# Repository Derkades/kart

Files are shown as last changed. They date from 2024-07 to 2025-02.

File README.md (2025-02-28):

# Kart

## Dashboard

Information and settings screen on steering wheel. PlatformIO project for STM32.

## Controller

Receives analog signal from acceleration/deceleration pedals (or rather, forwards and backwards pedals). The target speed/torque is sent to the two hoverboard controllers via serial, to ensure they both run at exactly the same speed.

## Hoverboard

Motor controllers (2x). For firmware see https://codeberg.org/raphson/hoverboard

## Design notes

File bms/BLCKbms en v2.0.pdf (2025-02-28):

# BLCKbms

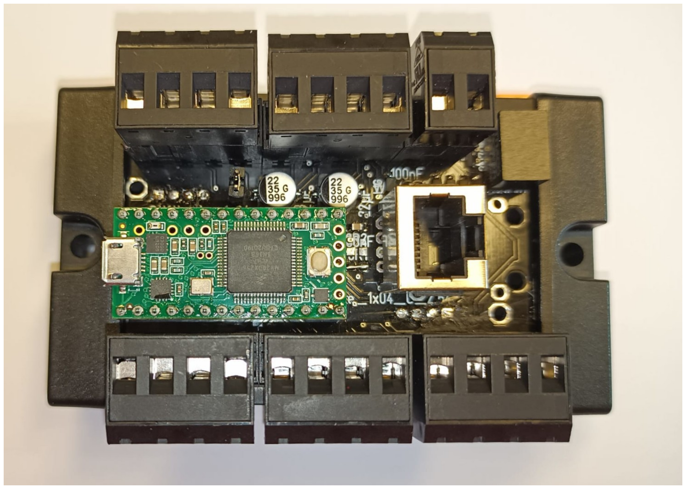
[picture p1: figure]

## 1 Table of Contents

## 2 Overview

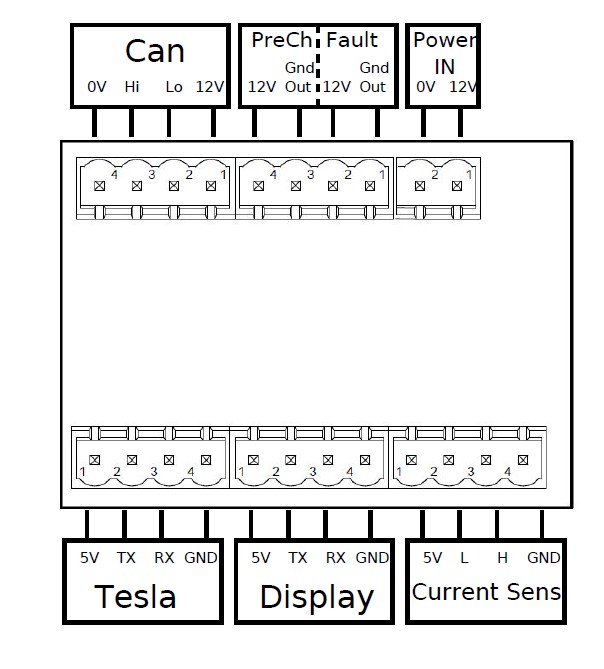
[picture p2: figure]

Manuel BMS Master | 2 von 4 | Ver 1.0

## 3 Interfaces for Second Life Batteries

The following interfaces are available with the BMS (see block diagram):

3.1 Tesla Interface

Connector BMS | Connector Tesla Modul
TX | 1. Modul PIN 2/7
RX | Last Modul PIN 4/9
+5V | PIN 5
GND | PIN 3

3.2 Can Interface:

Mitsubishi Outlander:

Connector BMS | Modul 1-x (Outlander) | Last Modul (Outlander)
12V | PIN 4 | PIN 4
GND | PIN 6 | PIN 6
Lo | PIN 1 | PIN 1 + PIN 8
Hi | PIN 5 | PIN 5 + PIN 2

BMW I3

Connector BMS | First I3 Pin | Next I3 Pin
5V | PIN 7 | PIN 1
GND | PIN 12 | PIN 6
Lo | PIN 10 | PIN 4
Hi | PIN 11 | PIN 5

Victron Wechselrichter

Connector BMS | Victron RJ45 | Aderfarbe Patchkabel
12V | PIN 2 + PIN 4 | orange + blue
GND | PIN1 + PIN 5 | blue/white + orange/white
Lo | PIN 8 | brown/white
Hi | PIN 7 | brown
Manuel BMS Master | 3 von 4 | Ver 1.0

## 4 Fault Output

This output switches in the event of overvoltage, undervoltage, overtemperature or undertemperature. With this output, the battery is to be switched off via a suitable switching device. The output (Out) is ground-switching. If a relay is connected, free-wheeling diodes have to be used.

## 5 PreCharge Output

## 6 Current sensor:

Connection Current Sensor: LEM DHAB S/161

Connector BMS | Connector | Description
L | D | Vout low current range
GND | C | GND
H | B | Vout high current range
5V | A | 5V
Manuel BMS Master | 4 von 4 | Ver 1.0

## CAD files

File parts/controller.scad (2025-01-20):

include <BOSL2/std.scad>

height = 100;
width = 170;
t = 0.8;
depth = 35;

difference() {
    union(){
        cuboid([width, height, t], anchor=BOTTOM);
        rect_tube(h=depth, size=[width+t*2, height+t*2], isize=[width, height], anchor=BOTTOM);

        up(depth-12.5)
        right(width/2)
        yrot(45)
        cuboid([20, height, t], anchor=TOP+RIGHT);
    }
    
    up(depth-12.5)
    right(width/2)
    yrot(45)
    cuboid([100, height+2*t, 20], anchor=BOTTOM);
    
    up(depth)
    cuboid([width, height, 10], anchor=BOTTOM);
}

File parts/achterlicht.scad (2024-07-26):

include <BOSL2/std.scad>

iw = 100;
ih = 52 + 2;
h = 10;
wall = 2;

// Kies een van de twee
//plate();
box();

module box() {
    difference() {
        cuboid([iw+wall*2, ih+wall*2, h], anchor=BOTTOM);
        
        translate([0, 0, wall])
        cuboid([iw, ih, h], anchor=BOTTOM);
        
        // tie wrap and cable holes
        for (x = [-iw/3, 0, iw/3]) {
            translate([x, -ih/2, 0])
            cuboid([6, 1.7, wall], anchor=BOTTOM+FRONT);
        }
    }
}

module plate() {
    translate([0, 0, h-wall/2])
    difference() {
        cuboid([iw, ih, wall/2], anchor=BOTTOM);
        
        // tie wrap holes
        for (x = [-iw/3, iw/3]) {
            translate([x, -ih/2, 0])
            cuboid([6, 1.7, wall/2], anchor=BOTTOM+FRONT);
        }
    }

}

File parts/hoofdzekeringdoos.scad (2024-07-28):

include <BOSL2/std.scad>

module screw_mount(hole_r, t) {
    difference() {
        cube([hole_r*4, hole_r*4, t], anchor=BOTTOM);
        cylinder(h=t, r=hole_r, anchor=BOTTOM);
    }

    for (y = [-hole_r*2+t/2, hole_r*2-t/2]) {
        translate([0, y, t])
        prismoid(size1=[hole_r*4, t], size2=[0, t], shift=[-hole_r*2, 0], h=hole_r*3);
    }
}

h = 30;
ol = 85;
ow = 35;
t = 2;
cutout_width = 15;
cutout_top_distance_from_left = 5;
cutout_height = cutout_width + h / 4;
screw_r = 2.5;

difference() {
    cube([ol, ow, h], anchor=BOTTOM);

    translate([0, 0, -t])
    cube([ol-t*2, ow-t*2, h], anchor=BOTTOM);

    // Left and right cutout
    for (x = [ol/2-t/2, -ol/2+t/2]) {
        translate([x, 0, 0])
        cube([t, cutout_width, cutout_height], anchor=BOTTOM);
    }
    
    up(h-1)
    fwd(5)
    scale(0.9)
    linear_extrude(2)
    text("hoofdzekering", anchor=BOTTOM);
}

// Screw mounts right
for (y = [ow/2-screw_r*2, -ow/2+screw_r*2]) {
    translate([ol/2+screw_r*2, y, 0])
    screw_mount(screw_r, t);
}

// Screw mounts left
for (y = [ow/2-screw_r*2, -ow/2+screw_r*2]) {
    translate([-ol/2-screw_r*2, y, 0])
    zrot(180)
    screw_mount(screw_r, t);
}

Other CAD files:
parts/spatbord.scad
parts/stuurscherm.scad

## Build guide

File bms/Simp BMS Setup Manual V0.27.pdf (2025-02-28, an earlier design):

SIMP BMS V2.3 | SimpEco Engineering
2021-08-20
simpecoeng@gmail.com | 1

# SIMP BMS

Manual V0.27

## Contents

Settings modified by sending “ ‘ID’ ‘New Value’ ” via the serial terminal, will refresh values in

## Disclaimer

Please read this manual and understand it, questions are allowed. You the purchaser of this product are responsible for installing this system yourself. You NEED knowledge of battery systems, automotive wiring and general computer knowledge.

THIS IS NOT A PLUG AND PLAY SYSTEM, USER CONFIGURATION AND WIRING REQUIRED

The device is provided "as is". Simp Eco Engineering makes no warranties, expressed or implied, and hereby disclaims and negates all other warranties, including without limitation, implied warranties or conditions of merchantability, fitness for a particular purpose, or non-infringement of intellectual property or other violation of rights. Further, Simp Eco Engineering does not warrant or make any representations concerning the accuracy, likely results, or reliability of the use of the materials in this manual or otherwise relating to such materials.

Damages
In no event shall Simp Eco Engineering or its suppliers be liable for any damages (including, without limitation, damages for loss of data or profit, or due to business interruption,) arising out of the use or inability to use the devices supplied by Simp Eco Engineering, even if Simp Eco Engineering or a Simp Eco Engineering authorized representative has been notified orally or in writing of the possibility of such damage.

Please contact the reseller that has provided you the SimpBMS first for support

## SimpBMS Purchase Overview

The standard items included in the purchase of a SimpBMS are:

- The SimpBMS board
- Teensy 3.2 flashed with requested Firmware

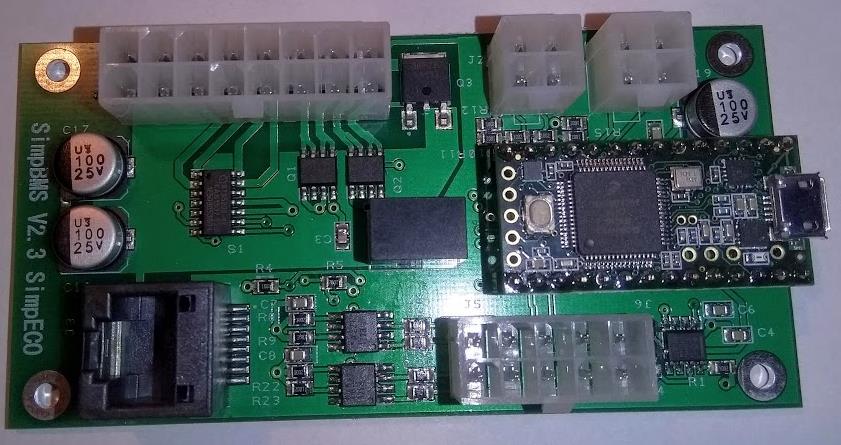
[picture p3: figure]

Optional available hardware at extra cost:
- Mating Connectors to the SimpBMS board with terminals

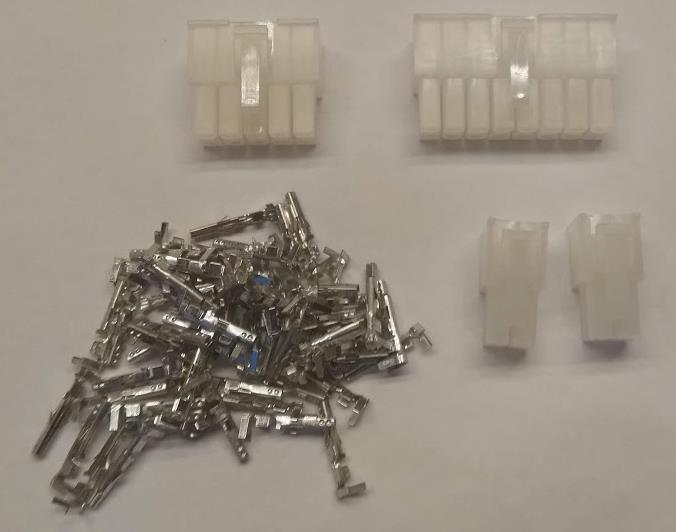
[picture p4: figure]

- Nextion 3.2 Inch Display with flylead, loaded with software to work with SimpBMS

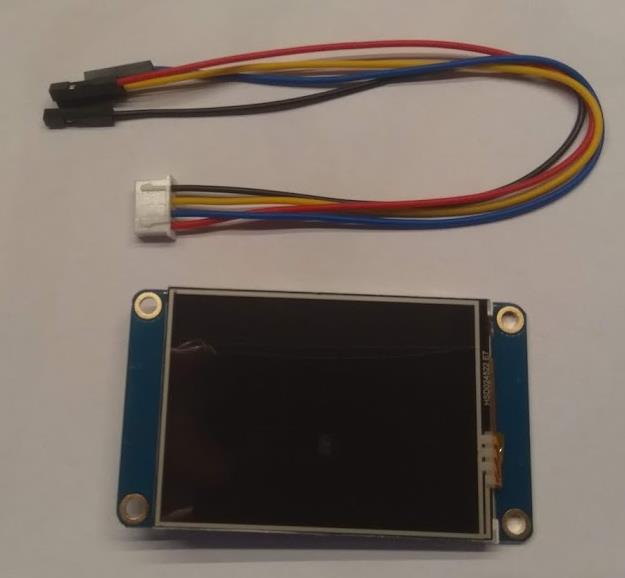
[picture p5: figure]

## Basics of the SIMP BMS

The starting point for this BMS is to keep it simple, the BMS will not prevent you from harming your battery if you do not set it up properly or ignore the limits it sends out.

### Currently supported slaves:

-Tesla Model S/X
-Tesla battery modules used in other OEM cars
-VW E-Golf and GTE (no balancing currently) -Mitsubishi Outlander
-BMW I3
-BMW Phev
-Chevy Volt / Opel Ampera Gen1

### Features:

Teensy 3.2 based
4 - 5-16V isolated inputs
4 - 12V outputs
4 - Low side switching outputs
2 - analogue current inputs (for dual range sensor)
1 - Serial bus for Tesla modules
1 - Canbus for communication with other modules, current senors or vehicle 1- Spare serial bus for expansion

### Current working features:

- Canbus communication formatted for Victron Systems
- Full Control of Slaves, reading temperatures and voltages plus controlling balancing
- Precharge control, timer and current based
- Can based current sensor (CAB300)
- AH Counter Based SOC calculation
- Voltage based SOC correction
- Watchdog timer to reset BMS in event of software error
- Canbus Chargers (Brusa NLG5xx, Chevy Volt, Elcon) -Display support (Nextion)

### Working Modes

Normal Operation (EV)

This mode will function as you would expect from a ‘key’ operated pack, such as found in vehicles. Precharge will happen with key on ect.

ESS Mode (stationary)

Specifically developed to cater to the needs of stationary or large packs
(dual purpose packs on boats for example)
When powered up Precharge occurs (no key in used) then contactors/relays used to control charge and discharge allowed. Also a Shunt trip or Main contactor output to disconnect packs when issues occur.

All features beyond output and input control are identical.

## Work in Progress

### EVSE controls

An interface circuit is being developed to allow the SimpBMS to directly interface with an EVSE via the Control Pilot line.

This will use the following pins (you can use more then one source of signal if needed)

1. AC present, 12V high when EVSE active and plugged in
2. Input 4 to sense duty cycle of the CP signal
3. Charge enable to request power from the EVSE

Functionality currently looking at supporting:

1. Enabling EVSE and charger if values allow
2. Managing the DC current limit based on AC current and Battery limits

## Detailed Workings

### Balancing

There is a small difference between ESS Mode and Normal Operation;

-ESS Mode always allows balancing based on balancing settings

-Normal Operation does not balance while in ‘driving’ operation state, this is due to the possibility of large voltage fluctuations due to high variation of loads.

For the working of balancing please see the setup page with the relevant parameters; Serial Interface / ‘b’ Battery Settings Menu

## Wiring Basics

Before starting on wiring your SimpBMS configuration it is best to get an understanding of the major components in your setup.

Ask yourself the following questions:

1. Do I want to have a EV or Storage (ESS) application
2. What devices are to be connected to the canbus network
a. Do these devices communicate at the same speed (example: 500KBPS) (see canbus chapter page 38)
b. Do these devices have canbus terminators in them
3. Will the BMS control the Contactors (see contactors chapter page 17)
4. What other inputs and outputs do I need (see inputs chapter page 19)

The most basic storage setup will have the following:

1. 12V power and ground into the SimpBMS connector J4
2. Battery module slaves connected to connector J5, see the specific page for each supported version
3. Connector J5 or J3 used to have canbus communication to the rest of the system, for example a Victron GX product

All other features can be considered “add-ons” getting the basic setup communicating properly is important to troubleshoot wiring and setting issues.

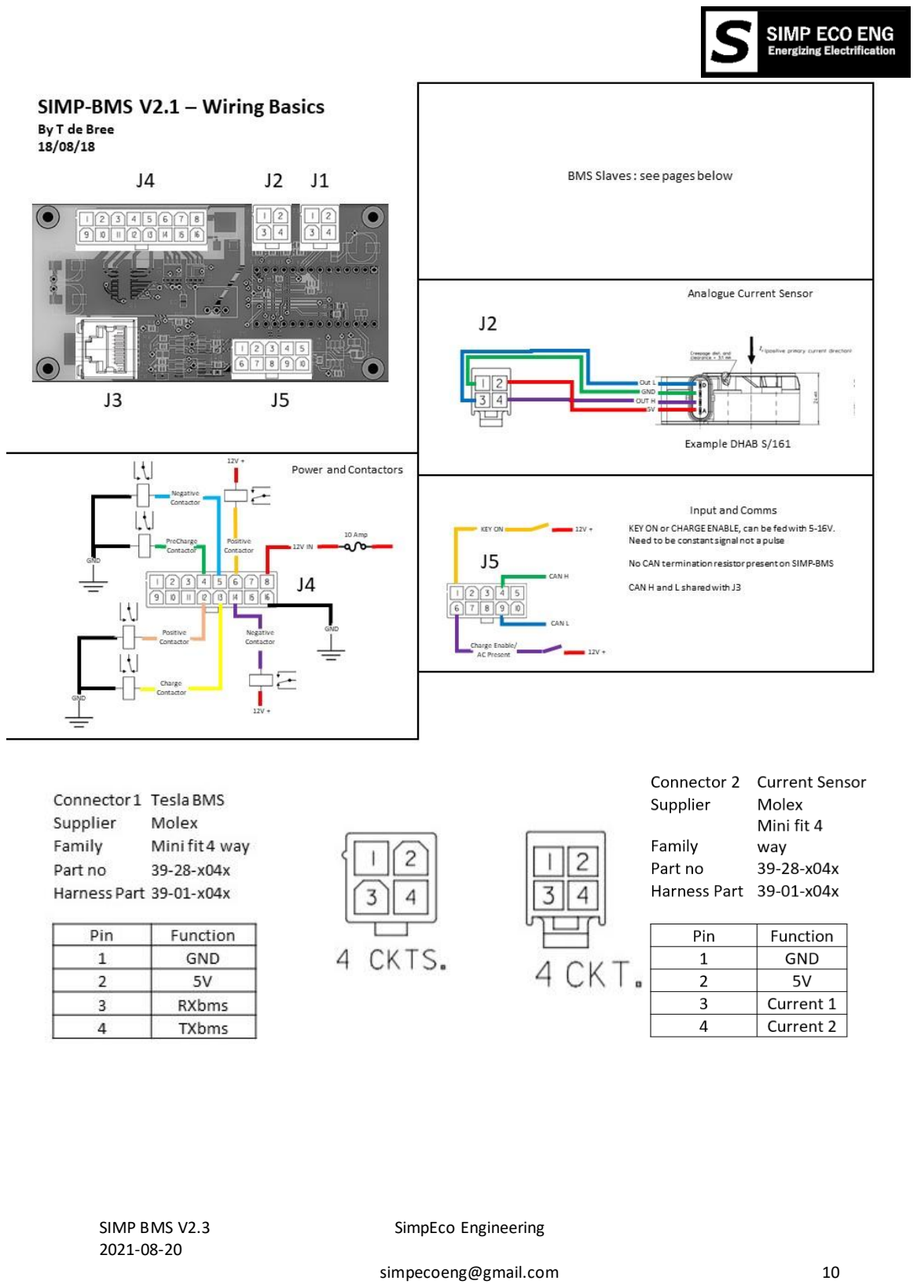
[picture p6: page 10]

2021

-08

-20

2021

-08

-20

Connector 5 Comms
Supplier | Molex
Family | Mini fit 8 way
Part no | 39-28-x10x
Harness Part 39-01-x10x
Pin | Function | Switching | Type | V2 Normal usage | ESS Mode | Function | Pin | Pin | Function 1 | In 1 | High | Input | Key on | Storage Mode | In 3 | 6 | 1 | In 1 2 | In 2 | High | Input | Alt Charge Current | - | In 4 | 7 | 2 | In 2 3 | Txspare | - | Comms | - | - | Rxspare | 8 | 3 | Txspare 4 | CanH | - | Comms | Can | Can | CanL | 9 | 4 | CanH 5 | 5V Out | - | Supply | - | - | GND | 10 | 5 | 5V 6 | In 3 | High | Input | AC present | - 7 | In 4 | High | Input | CP cond signal | - 8 | Rxspare | - | Comms | - | - 9 | CanL | - | Comms | Can | Can
10 | GND | - | Ground

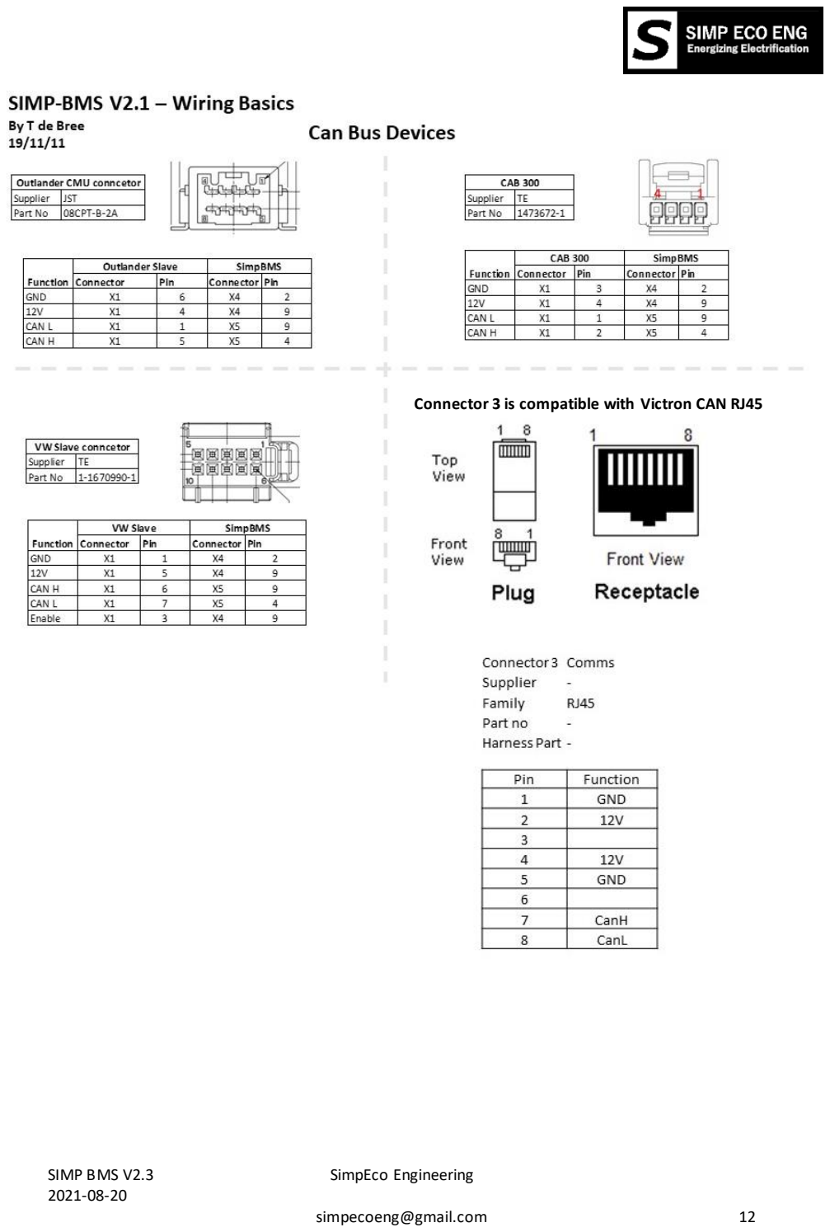
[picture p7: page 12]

Connector 3 is compatible with Victron CAN RJ45

### Tesla Slave Wiring

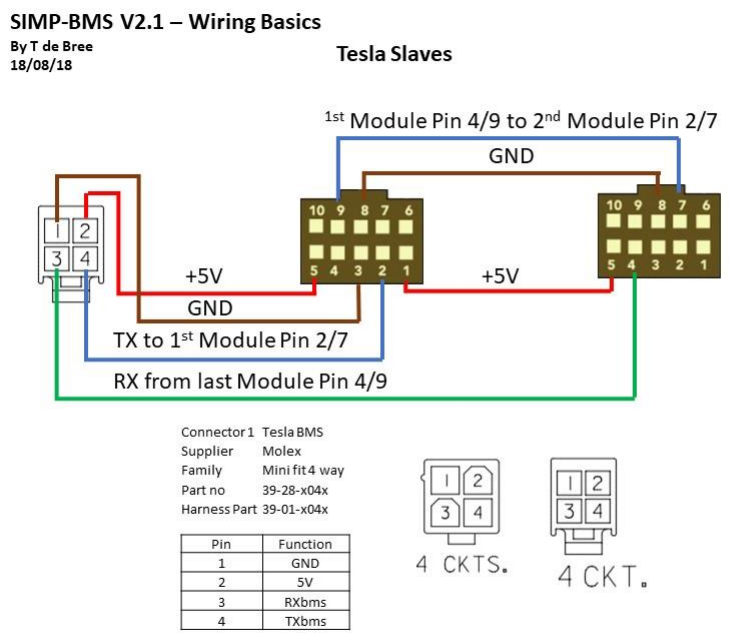
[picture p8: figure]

### Chevy Volt Gen1 Slaves

The battery master, located in front of the Chevy Volt Gen 1 pack is connected to the internal network with the slaves and current sensor.

Connector looks as below:

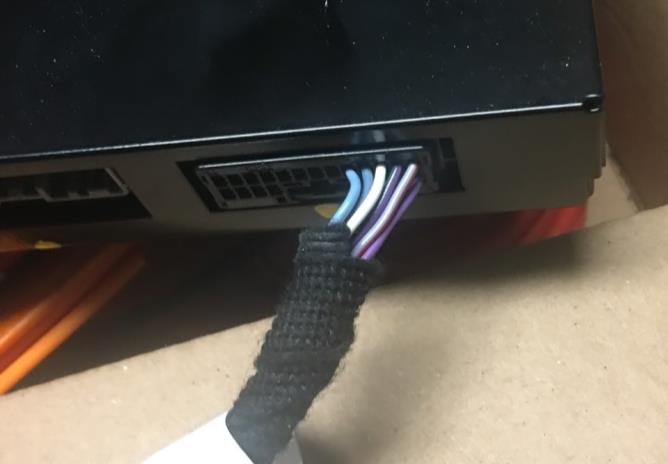
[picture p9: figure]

BMS Slaves

Pin | Function | Color | SimpBMS connection
9 | 5V supply | Grey/Red | J5-5
10 | Ground | Black/Purple | J5-10
11 | Can Low | White Yellow | J5-9
12 | Can High | Light Blue/Yellow | J5-4
13 | - | Light Blue | -

Current Sensor - dhab s44

Pin | Function | Color | SimpBMS connection
1 | 5V supply | Purple/Red | J2-2
2 | Ground | Black/Grey | J2-1
3 | High Range | Light Blue/Yellow | J2-3
4 | Low Range | Light Green/Brown | J2-4

Configuration:

Current Sensor Type: Dual Range

Low Range : 100 mV/A

High Range : 6.15 mV/A

### Mitsubishi Outlander CMUs

Up to a full pack can be used, it is not possible to use more because of the assigned Can Bus Ids per module.

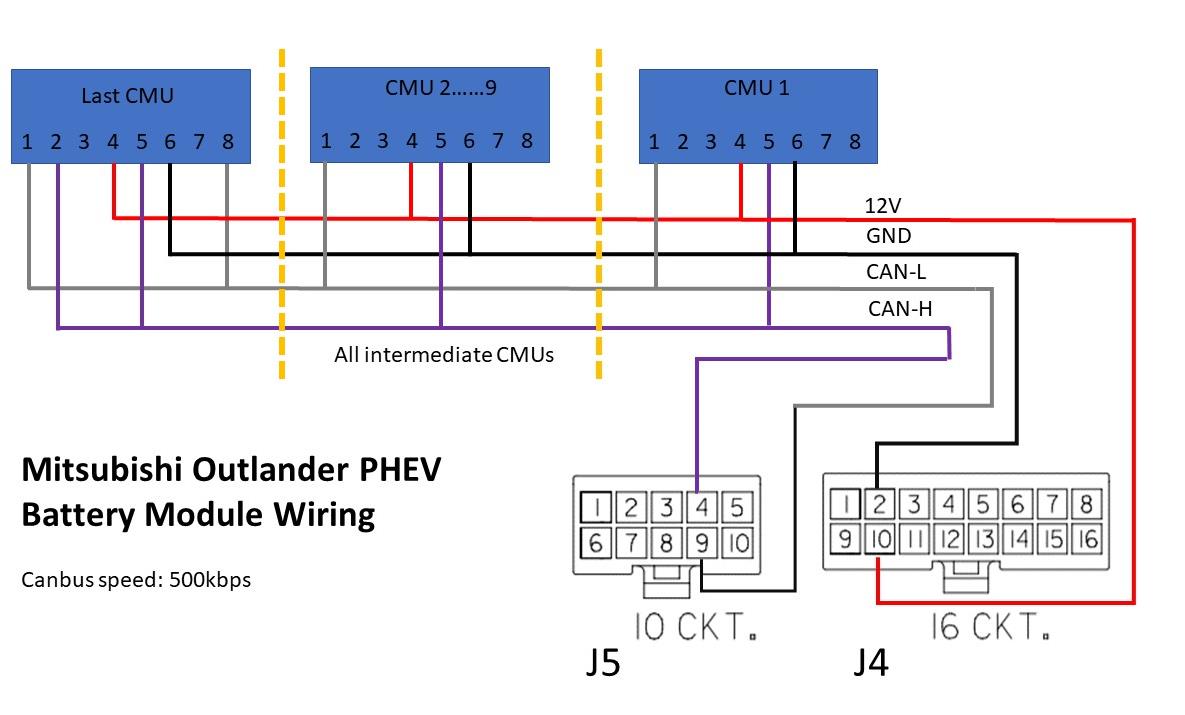
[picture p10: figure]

### BMW I3 CSC modules

Up to a full pack can be used, it is not possible to use more because of the assigned Can Bus Ids per module.

wiring
Designed to be Daisy chained from one module to the next, remember to close the end canbus by having a 120 ohm resistor between canH and canL.
BMW I3 Pin | Function | Color | SimpBMS connection
1 | 5V supply | Grey/Red | J5-5
6 | Ground | Black/Purple | J5-10
4 | Can Low | White Yellow | J5-9
5 | Can High | Light Blue/Yellow | J5-4

If using more then one module you can just do the following:

First BMW I3 Pin | Function | Next BMW I3
7 | 5V supply | 1
12 | Ground | 6
10 | Can Low | 4
11 | Can High | 5

If you use the full pack you can interface to the “Master” connector

Master plug pin | Function | Colour | SimpBMS connection
5 + 11 | 5 V supply | Red/white | J5-5
6 + 12 | Ground | White/brown | J5-10
8 | Can low | Yellow/brown | J5-9
7 | Can high | Yellow/red | J5-4
1 + 2 | Resistor 120 ohm | Yellow/brown and Yellow/red | 120 Resistor between

Extra info on individual module slaves

| BMW i3 Slave Connector
Function | 5V Power | | ? | CanL | CanH | GND
Wire | Red/White | NC | Blue | Yellow/Brown | Yellow/Red | White/Brown
Pin | 1 | 2 | 3 | 4 | 5 | 6
Pin | 7 | 8 | 9 | 10 | 11 | 12
Wire | Red/White | NC | Blue | Yellow/Brown | Yellow/Red | White/Brown
Function | 5V Power | | ? | CanL | CanH | GND

## Outputs and Inputs

### Contactors

It is possible to use both contactors with built in economizers or without.

Contactors with built in economizers MUST be used on the 12V switched outputs

Contactors without built in economizers MUST be used on the ground switched PWM outputs

See for the circuit below, a diode must be used in parallel with the contactor.

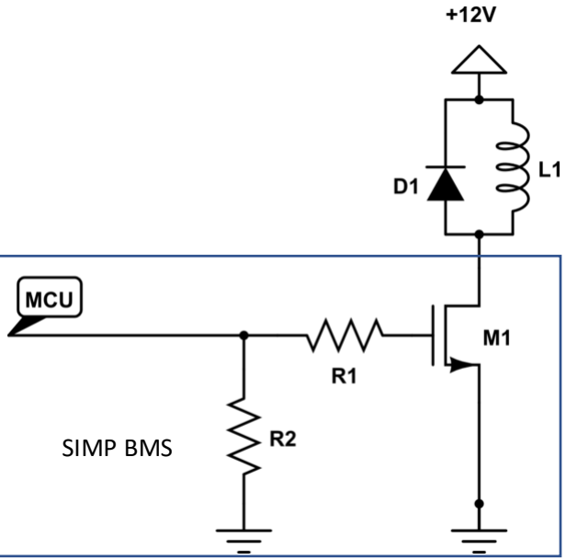
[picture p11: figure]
SIMP BMS

### Contactor behavior

ESS Mode:

Delay on the Low switching contactor outputs can be set via precharge delay

Function | Switching | Pin | ESS switching behaviour
Charge | High | 13 | Instant
DisCharge | High | 12 | Instant

These outputs are meant to control dumb loads and chargers/sources.

The other outputs to ‘Trip Shunt’ or ‘Main Contactor’ mode

### Trip Shunt

In ESS mode OUT2 can be used to trip DC breakers with a shunt trip device. This output goes high when an over or under voltage or over temperature situation occurs.

Make sure the shunt is rated for the activation signal of 12V.

Function | Switching | Pin | ESS switching behaviour
Shunt Trip | High | 4 | Instant
Not Used | High | 5 | NOT USED

### Main Contactor

In ESS mode you can choose to have a single contactor to connect and disconnect the battery.

When an over or under voltage or over temperature situation occurs the battery gets disconnected. If these faults are not present the battery is allowed to connect.

Function | Switching | Pin | ESS switching behaviour
Main Contactor | High | 4 | Switches on after precharge
Main Contactor | Low | 6 | Switches on after precharge
Precharge | High | 5 | Switched on for duration of precharge delay

### Inputs

Inputs are triggered by giving them anywhere from 5-16V, the inputs are isolated from the micro controller but must share the same ground as 12V in.

EV Mode:

Pin | Name | Function
1 | Key-on | Request BMS to close contactors and go into ‘Drive’ mode via precharge
6 | AC-present | Request BMS to go into charge mode and command charger
2 | Charge Current | Not connected – standard limit / HIGH is alternate limit
7 | CP conditioned | Control Pilot signal monitoring (future implementation)

ESS Mode:

Pin | Name | Function
1 | Storage Mode | Charge Voltage now reduced to parameter ‘Storage Setpoint’

### Wiring contactors into BMS or Not

Depending on your setup you can decide to have the contactors controlled by the BMS or by the Inverter/Drive unit.

Please keep in mind:

- Tripping contactors with rotating motors can/will damage the inverter
- The BMS is meant to protect the batteries and not other items
- Wiring items directly to the battery can cause drain that can irreversibly damage the batteries.

If your motor controller/inverter can control the contactors use this. Wire the BMS positive contactor 12V output to control a relay that can cut the enable signal to the motor controller/inverter to protect the batteries. This signal can also be used for a ‘Ready’ light on the dash for a visual indication.

Depending on the charger you can wire it directly to the battery or via a single contactor depending on the type of charger used, some require pre-charging.

### Wiring up BMS Slaves

When reusing existing vehicle battery modules might not be possible to parallel them at cell level.

The approach that thus can be taken is to wire all the modules in series and then parallel the strings to create the complete pack.

Values to determine for your setup:

Battery Capacity – Capacity of parallel cells monitored by BMS Slave

slaves in parallel – How many battery strings are connected in parallel

Cells in Series – total amount of cells that are in series in a string

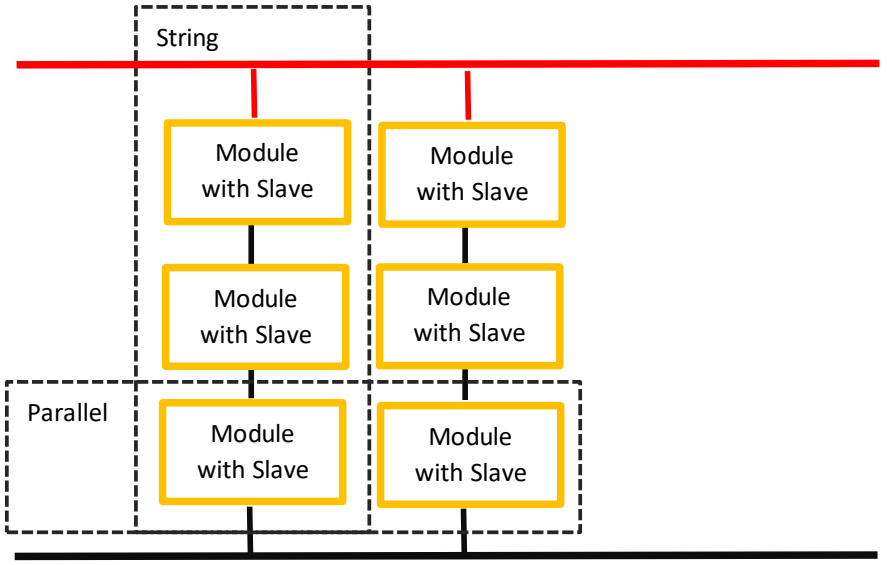
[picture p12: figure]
String; Module with Slave; Parallel

### Wiring up Nextion Display

A Nextion Display programmed with the appropriate software will allow the displaying of information provided by the SimpBMS.

The required connections are on connector 5.

Connector 5 | Signal BMS | Connection Display
5 | 5V supply | 5V
10 | Ground | Ground
3 | RXspare | TX
8 | TXspare | RX

Nextion Display Connection

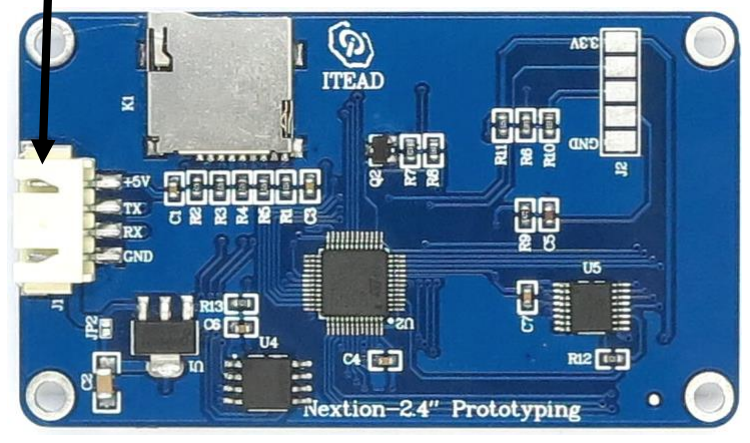
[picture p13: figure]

### Upgrading Nextion display firmware

There are two ways to do this;

1. Utilizing the Nextion editor and provide .HMI file found here: https://github.com/Tom-evnut/SimpDisplay
2. Saving the “.tft” file onto an SD card, insert into display, power cycle display and wait for update to complete.

### Wiring up Chargers

SimpBMS can control chargers in various ways:

- Simple on/off control with a relay
- Can bus controlled with a relay as back up (Can Bus info in the Can Bus Chapter)

Depending on how your charger is connected to your pack you can enable the HV contactors closing if required.

Below is an simplified diagram, this is for illustration only.

If the charger is directly connected to the battery, like the green lines show, the contactors do not need to close in order to charge.

The variable ; Charger HV Connection would be set to Direct To Battery HV

If the charger is connected to the HV bus after the contactors, the blue lines;

The variable ; Charger HV Connection would be set to Behind Contactors

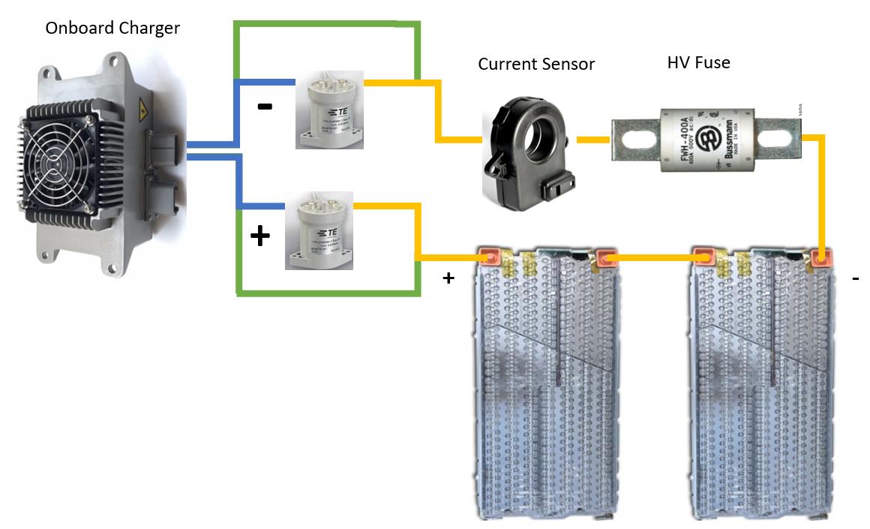
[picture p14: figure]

### Connection to Victron Color Control

Connector 3 on the SimpBMS is compatible with the VE.Can rj45, this means that you can use a standard ethernet cable to join the two. Please bear in mind that for VE.Can to work it requires a termination resistor to be added on the second VE.Can port on a color control.

Victron VE.Can terminator: https://www.victronenergy.com/accessories/ve-can-rj45-terminator

The SimpBMS will still require to be powered by an external 12V source.

Example connection to a Color Control GX

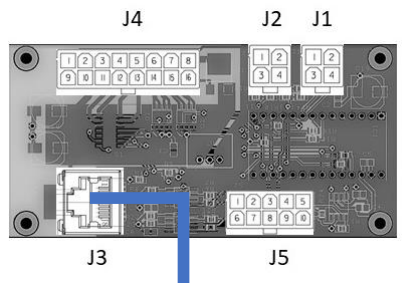
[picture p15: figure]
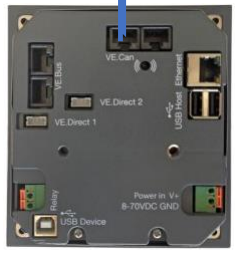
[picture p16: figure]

The GX control needs to be configured to 500kbps so it can receive the data from the SimpBMS.

The SimpBMS should show up as an available Battery monitor on the GX.

A good start for further workings of a Can based BMS in the Victron system : https://www.victronenergy.com/live/ccgx:start

## Serial Interface

How to connect to SIMP BMS.

1. Connect the Micro-B USB port on the teensy to your computer with appropriate cable
2. Computer should identify new usb/serial device
3. Open your preferred Serial Terminal Program. Example : https://www.compuphase.com/software_termite.htm
4. Connected to the Simp BMS via the serial port (115200 BAUD)
5. Now you should see the ‘Debug’ screen info scrolling

Any issues with connecting please check the Teensy Microcontroller troubleshooting guide:

https://www.pjrc.com/teensy/troubleshoot.html

If the Teensy does not show up as serial port please run the Teensy Serial installer https://www.pjrc.com/teensy/serial_install.exe

### Diagnostic Info Screen

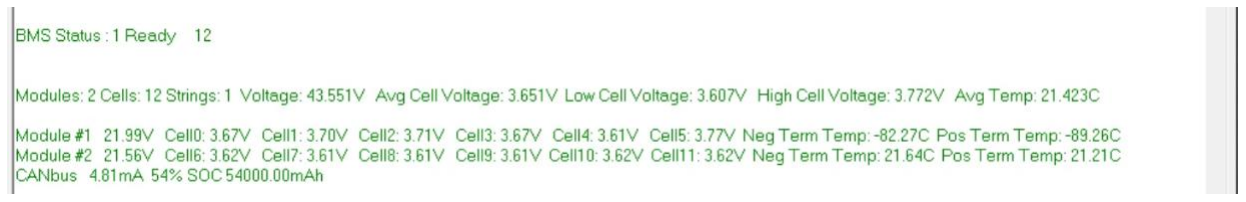
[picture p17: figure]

BMS Status : this is what state the bms is in.

Ready : BMS is good and communicating normally, waiting for a drive or charge digital input

Mode that is suggested for a fixed storage solution

Error : A fault is present in the read out from the modules. Possible issues:

Overvoltage

Under voltage

Overtemperature

Under temperature

Precharge : when Key on is high this is initiated, drives the negative contactor and then the precharge contactor. Once Precharge Timer (5000mS) has ran out AND the current drops below 1000mA it will close the contactor.* This initiates transition into drive.

Drive : Monitors voltages and temperatures with negative and positive contactor closed.

If key on signal goes low both contactors turn off immediately and BMS goes into Ready state.

Transition to error state if : under voltage is detected

Temperature currently only derates the transmitted current limits

Charge: When AC present in is high the charger enable output gets turned on until end of charge is reached or error occurs.

When one cell hits the overvoltage it will stop charging and go to ready.

Rest of displayed information is shown per module, both voltage and temperatures reported

Plus a summary of totals and averages based on pack settings

To open setup send the command: s

### Simp BMS Setup Menu

Not al variants have the same parameters or menus.

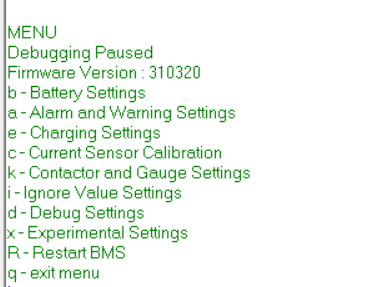
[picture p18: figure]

This stops the scrolling of the diagnostics info.

This shows the Firmware Version Number, please indicate this when ever requesting support.

And displays the following options:

b - Battery Settings

a - Alarm and Warning Settings

e - Charging Settings

c - Current Sensor Calibration

k – Contactor settings and Gauge Settings

i – Ignore Value Settings

d - Debug Settings

x-Experimental Settings

R – Restart BMS

q - exit menu

### ‘q’ Quit

Exit the setup menu and resume diagnostics display info

### ‘d’ Debug Settings

Inputting a number of the shown options toggles the modes, to stop send the same number.

1 – Can Debug = show can messages

2 – Current Debug = show all the current calculation information

3 – Output Check = cycle outputs !!! DO NOT TURN ON WITH HV CONNECTED TO CONTACTORS

4 – Input Check = show level of all inputs

5 – ESS Mode = turn on and off ESS Mode, ON is 1

6 – Cells Present Reset = recalibrate the cells to check if they are present

7 – Gauge Debug = cycle the gauge output up and down for testing pwm settings for gauge

8 – CSV Debug = Data is now displayed in a Comma Seperated Values makes logging it easier

9 – Decimal Places to Show = how many decimals to show for cell voltage debug

q – go back a menu

### ‘b’ Battery Settings Menu

Settings modified by sending “ ‘ID’ ‘New Value’ ” via the serial terminal, will refresh values in terminal

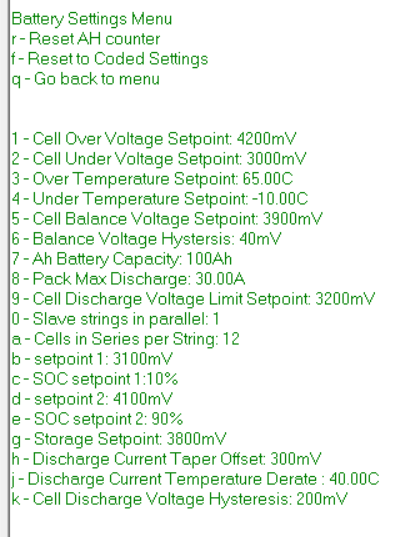
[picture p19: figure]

r – Reset AH Counter = Use voltage to determine SOC, best used with open circuit voltage

f – Reset to coded settings, the settings that were written when the code was compiled

1 – Over Voltage Setpoint = Over voltage limit per cell in mV

2 – Under Voltage Setpoint = Under voltage limit per cell in mV

3 – Over Temperature Setpoint = Setpoint at which allowed discharge and charge current is reduced to zero

4 - Under Temperature Setpoint = Setpoint at which allowed discharge and charge current is reduced to zero

5 – Balance Voltage Setpoint = Setpoint of cell voltage in mV at which during charging cells will start balancing.

6 – Balance Voltage Hysteresis = Voltage required to be above the lowest cell to allow balancing of cell in mV

7 – Battery Capacity = each group of parallel cells monitored per slave capacity in Ah

8 – Max Discharge = maximum discharge current in A, transmitted current limit will taper from max current starting at discharge temp to zero at over temperature.

9 – discharge voltage limit = used to calculate max discharge setpoint, voltage per cell will get converted to pack level by BMS

0 – slaves in parallel = amount of slave strings in pack (will multiply total pack capacity)

a – cells in series = amount of cells in series (per string if wired in parallel)

b - mV setpoint 1 = cell voltage setpoint 1 for voltage based SOC calc

c - SOC setpoint 1 = SOC for corresponding cell voltage

c- mV setpoint 2 = cell voltage setpoint 2 for voltage based SOC calc

e- SOC setpoint 2 = SOC for corresponding cell voltage

g – Storage Charge Voltage setpoint = when in Storage mode in ESS this is used instead of Charge Voltage Limit

h – Discharge Current Taper Offset = the voltage offset from Discharge Voltage Limit at which the discharge current Max will start to taper down.

j – Discharge Current Temperature Derate = Temperature above which discharge current starts to taper to 0 Amps at Over Temperature

k – Cell Discharge Voltage Hysteresis = cell voltage needs to rise this amount above the Discharge Voltage Limit before discharge is allowed again in ESS mode

### ‘e’ Charging Settings

Settings modified by sending “ ‘ID’ ‘New Value’ ” via the serial terminal, will refresh values in terminal

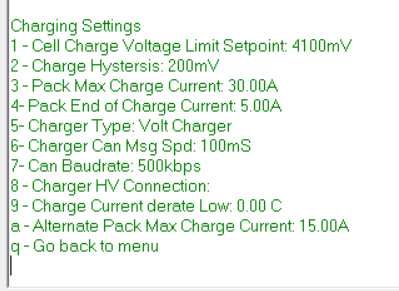
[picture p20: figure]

1 – Cell Charge Voltage Limit = End of charge voltage target for cells

2 – Charge Hysteresis = Drop in cell voltage required to restart charging

3 – Pack Max Charge Current = Max allowed charge current into pack

4 – Pack End of Charge Current = Current when reaching target voltage, tapers based on hysteresis

5- Charger Type = Switch can bus controlled charge output messages (Cyclic)

Relay Control – Turn output on and off

Brusa NLG533 – On standard Control Ids

Volt Charger

Eltek Charger – Volvo versions also supported

Victron Charger

6- Charger Can Msg Spd = Interval target between sent can messages

ONLY FOR TESLA FIRMWARE 7 – Can Baudrate = Can network speed, to be changed to match other items on Can network, see for information the chapter on Can. Will only take effect after exiting the menu’s fully and then doing a powercycle.

8 – Charger HV Connection = How does the charger connect to the pack

Direct To Battery HV – connected directly to the battery pack (through a fuse ofcourse)

Behind Contactors – connected onto the main HV bus after the contactors, so during charging contactors need to be closed.

9 – Charge Current derate Low = Temperature under which the Charge Current will derate, it will reach zero at Under Temperature

a – Alternate Pack Max Charge Current = when pin is toggled high this is the newly enforced Max Charge Current

### ‘c’ Current Sensor

Settings modified by sending “ ‘ID’ ‘New Value’ ” via the serial terminal, will refresh values in terminal

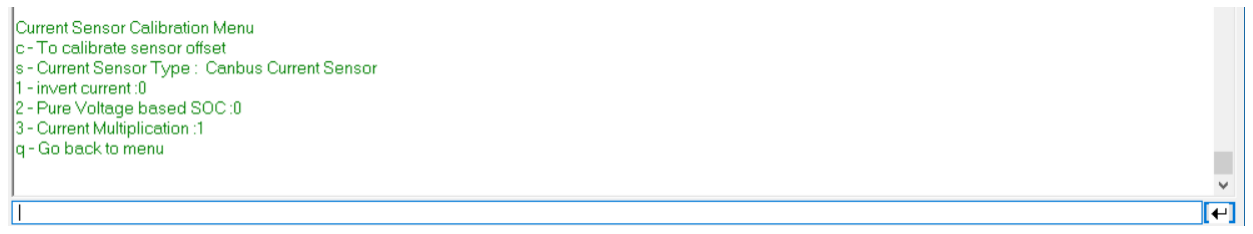
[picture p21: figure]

c - To calibrate sensor offset = for calibrating analogue sensor offsets*

s - To switch between Current Sensors = switches between sensors types

Undefined = OFF

Analogue Dual Sensor = dual range 5V output sensors

CanBus Sensor = CAB300 or CAB500 supported over CAN

Analogue Single Sensor = single range 5V output sensors

1- Invert current = if current sensor is reading the wrong direction toggle value
2- Pure Voltage SOC = do not use coulomb counting and rely on using cell voltage to do SOC

Recommend for large packs with low discharge and charge currents

3 – Current Multiplication = 1 if all current goes through the sensor , 2 if only one cable (identical required) passes through the sensor and two are used on one pole.

q - Go back to menu

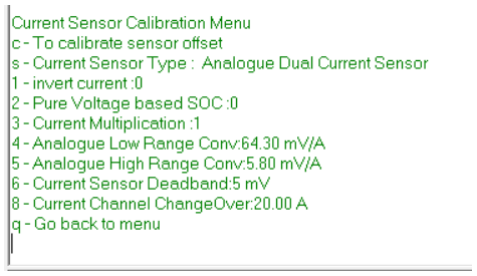
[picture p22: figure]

4 – Analogue Low Range Conv = value for conversion mV/A, enter 10x.

5 – Analogue High Range Conv = value for conversion mV/A, enter 10x.

6 – Current Sensor Deadband = voltage around the zero point which the measurement will be ignored

8 – Current Channel ChargeOver = at which current level will the alternate channel be selected

### Configuring an Analogue Current Sensor

When configuring an Analogue Current Sensor it must be kept in mind that analogue sensors all will have drift and variation due to their implementations/wire runs/emc influences.

Data required from manufacturer:

1. Single or Dual Channel
2. Resolution of each channel in mV/A on a 5V reference
3. If a dual channel limit of lowest channel

Select the variant of Analogue Current Sensor you are using, single or dual channel by cycling through the types using ‘s’.

When the system is powered on but no current is flowing through the sensor you are required to run the command ‘c’ to calibrate current sensor.

This will now report back some values which are written to the memory logging where the middle point is thus zero current point.

You now need to input each channels resolution in parameter 4 and 5.

You can leave the current sensor dead band at 5mV to start, you can later tweak this value to suit your system and sensor.

If you are using a dual channel sensor please input the current limit of the lower range in parameter 8.

Now completely exit the Setup menu using the command ‘q’ twice, this saves the parameters.

Go back into the setup menu and enter the debug screen and use the current debug option to view the reported values against a known current, keep in mind that a device you are using to determine what the current should be might have a different way of filtering the values.

Try a few points to get an indication of the deviation.

A current value lower than expect decrease the value for the resolution.

A current value higher than expected increase the value for the resolution.

### ‘k’ Contactor Control

Settings modified by sending “ ‘ID’ ‘New Value’ ” via the serial terminal, will refresh values in terminal

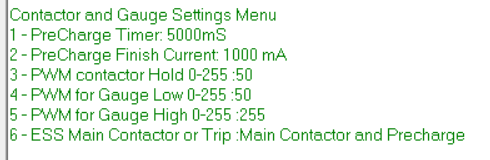
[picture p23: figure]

1 – Precharge Timer = mS of minimum precharge time

2 – Precharge Finish Current = mA of allowed current before switching in the main contactor

3 – Pwm contactor Hold = PWM duty cycle (values 0-255), lower the value the lower the ‘voltage’ at the contactor. This only works on the PWM pull low outputs.

Contactors without an internal coil require an diode placed across their ground and 12V feed, as depicted below, the coil is the contactor.

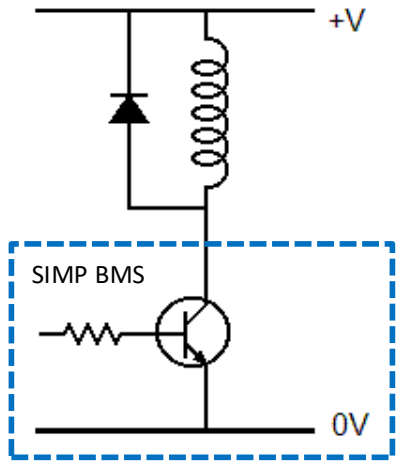
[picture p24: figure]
SIMP BMS

### Settings up an Analogue Gauge

The principle of the gauges driver is identical to that of the grounding contactor control.

Please make sure that your gauge works with a grounding signal, usually indicated by the original sensor having a signal connection and a ground connection.

This output can also be used with a setup the expects a voltage signal, all that needs to be done then is to have a 1K ohm pull up resistor to 12V so that the grounding output can put it to ground at varying duty cycles to generate an average voltage.

When a parameter is entered for a gauge value the gauge will snap to this position until the setup menu has been exited.

4 – PWM for Gauge Low = PWM duty cycle of Gauge Output to reflect 0% SOC

5 – PWM for Gauge High = PWM duty cycle of Gauge Output to reflect 100% SOC

6 - ESS Main Contactor or Trip = utilize a precharge and main contactor or a shunt trip setup only available in ESSmode

### ‘a’ Alarms and Warnings Settings Menu

Settings modified by sending “ ‘ID’ ‘New Value’ ” via the serial terminal, will refresh values in terminal

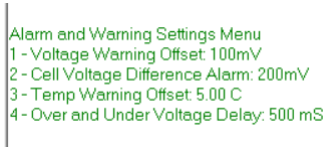
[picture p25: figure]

1 – Voltage Warning Offset = Offset from Under and Over Voltage limits when an Alarm Flag gets set

2 – Cell Voltage Difference Alarm = Difference below low and high cell to trigger Alarm Flag

3 – Temp Warning Offset = Offset from Over Temperature limit when an Alarm Flag gets set

4 – Over and Under Voltage Delay = the time allowed for cells to be exceeding limits, Overvoltage and Undervoltage, this is used to allow sag exceeding these limits for heavy discharges or inrush currents during turn on. Set in mS, please keep in mind that slaves might not be read at a very high frequency thus you should allow enough time for reading to be done.

### ‘i’ Ignore Value Settings

Settings modified by sending “ ‘ID’ ‘New Value’ ” via the serial terminal, will refresh values in terminal

1 – Temp Sensor Setting = Sensor to use, 0 is use all

2 – Voltage Under Which to Ignore Cells = to allow missing cells and then mask false readings

## Common Setup Issues and Errors

### Series Cells Fault

When the errors “series cells fault” is shown it means that the BMS is expecting more or less cells to be present.

Fix: check your settings for parallel strings and Cells in series with your actual connected setup, correct these numbers to make the error disappear.

If not resolved please check that all slave modules are recognized and communicating, if not please troubleshoot communications first.

## CANBUS

SIMP BMS will communicate on the canbus at the following speeds (baudrates)

Firmware | Baudrate [kbps]
Tesla | Programmable
Outlander | 500
Imiev | 500
Volt/Ampera gen1 | 125
VW | 500
BMW | 500

This is used to communicate with the following devices:

- Outlander BMS slaves
- Panasonic BMS slaves
- Volt Gen 1 BMS Slaves
- Can Current sensor
- Victron VE-CAN
- Can Bus based Chargers
- Other devices

### Termination Resistor

SIMP BMS does not come with a termination resistor as standard does come with a location for a 0805 resistor to add one.

If you measure the resistance across CanH and CanL if it is not 60 Ohm add a 120 Ohm resistor at the SIMP BMS connector. If the resistance is still too high add a 120 Ohm resistor at the other end of the can bus.

### Canbus Expansion

The canbus expansion module currently only works with the Chevy Volt / Opel Ampera software.

This allows you to run chargers and DCDC on a bus that is not locked at 125kbps for the slaves.

The Expansion Module plugs into J1, then wire the canbus High and Low into the screw terminal on the module.

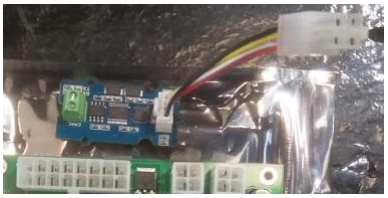
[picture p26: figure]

### Outlanders BMS SLAVES

It is only possible to use slaves with unique IDS, so maximum of 10 slaves before a trick is required.

Each slave can monitor 8 (10 possibly) parallel cell groups

### CAN Current Sensor

Only one current sensor per SIMP BMS

CAB 300
Bi-directional 350A max

Canspeed : 500kbps

### VW/Panasonic BMS Slaves

It is only possible to use slaves with unique IDS, so maximum of 8 slaves before a trick is required.

Each slave can monitor 12 parallel cell groups

### Chevy Volt BMS Slaves

Can only talk to a complete pack at most, cannot add any more slaves.

### Victron VE-CAN

Communicate using the simple protocol as REC BMS, will share all required information from the batteries.

You can set the Victron GX systems up to accept 500 or 250 kbps.

### Can Bus Controlled Charger

Currently the following chargers are supported, please note the associated can speeds these need to match everything else on the network.

Charger | Baudrate [kbps]
Eltek | 500 (possibly changeable)
Brusa NLG5xx | 500 default (configuration possible)
Chevy Volt/ Opel Ampera | 500
TCcharger /Elcon | 250 default (500 available from factory)
Coda | 500

### Other CAN Devices

Other devices can be connected, these can be setup to display and react to messages from the SIMP BMS.

CAN Messages
Message | Limits
Message ID | 0X351
Byte | Bit | Signal | Scale | unit
0 | | Charge Voltage LSB | 0.1 | A
1 | | Charge Voltage MSB | 0.1 | A
2 | | Charge Current LSB | 0.1 | V
3 | | Charge Current MSB | 0.1 | V
4 | | DisCharge Current LSB | 0.1 | A
5 | | DisCharge Current MSB | 0.1 | A
6 | | DisCharge Voltage LSB | 0.1 | V
7 | | DisCharge Voltage MSB | 0.1 | V
Message | SOC
Message ID | 0X355
Byte | Bit | Signal | Scale | unit
0 | | SOC LSB | 1 | %
1 | | SOC MSB | 1 | %
2 | | SOH LSB | 1 | %
3 | | SOH MSB | 1 | %
4 | | SOC LSB | 0.01 | %
5 | | SOC MSB | 0.01 | %
6 | | -
7 | | -
Message | Status
Message ID | 0X356
Byte | Bit | Signal | Scale | unit
0 | | Voltage LSB | 0.01 | V
1 | | Voltage MSB | 0.01 | V
2 | | Current LSB | 0.1 | A
3 | | Current MSB | 0.1 | A
4 | | Temperature LSB | 0.1 | C
5 | | Temperature MSB | 0.1 | C
6 | | -
7 | | -

Message | Warnings
Message ID | 0X35A
Byte | Bit | Signal
0 | 3 | Undervoltage
| 4 | Overvoltage
1 | 7 | Overtemp
2 | 12 | Undertemp
3 | | -
4 | | -
5 | | -
6 | | -
7 | | -
Message | Low and High
Message ID | 0X373
Byte | Bit | Signal | Scale | unit
0 | | Min Cell Voltage LSB | 1 | V
1 | | Min Cell Voltage MSB | 1 | V
2 | | Max Cell Voltage LSB | 1 | V
3 | | Max Cell Voltage MSB | 1 | V
4 | | Min Temperature LSB | 1 | Kelvin
5 | | Min Temperature MSB | 1 | Kelvin
6 | | Max Temperature LSB | 1 | Kelvin
7 | | Max Temperature MSB | 1 | Kelvin

## Firmware Updating

Updating firmware can be done with the simple process explained below, CHECK SETTINGS once you flash the new firmware. The process can alter memory locations and thus corrupt settings.

### Links

Latest files available on Github, including uncompiled code.

Tesla Github : https://github.com/Tom-evnut/TeslaBMSV2

Outlander Github :

https://github.com/Tom-evnut/OutlanderPHEVBMS/tree/master/OutlanderBMSV2

VW Github: https://github.com/Tom-evnut/VW-bms/tree/master/VWBMSV2

BMW I3 Github: https://github.com/Tom-evnut/BMWI3BMS

BMW Phev Github: https://github.com/Tom-evnut/BMWPhevBMS

Chevy volt / Opel Ampera Gen1 Github: https://github.com/Tom-evnut/AmperaBattery

### Flashing the HEX

The easiest way to get new firmware onto the SIMP BMS is by uploading the latest ‘ino.hex’ file

Example file name: TeslaBMSV2.ino.TEENSY31.hex (https://github.com/tomdebree/TeslaBMSV2/blob/master/TeslaBMSV2.ino.hex)

In order to get the hex onto the Teensy (microcontroller of the SIMP BMS) it is required to have Teensy Loader installed.

Please follow instructions on the PJRC website : https://www.pjrc.com/teensy/loader.html

Once installed and having downloaded the latest hex onto your computer follow the following steps to update the firmware:

6. Power down the system SIMP BMS is part of
a. This means turning off all chargers and loads attached if these are controlled by the SIMP BMS
7. Connect the Micro-B USB port on the teensy to your computer with appropriate cable
8. Open Teensy Loader “teensy.exe’
9. Go ‘file’ , ‘Open HEX File’ and select the just obtained firmware HEX
10. Program your SIMP BMS by clicking the arrow curved down (‘Program’ button)
a. If buttons not available hit press the reset on button on the Teensy on the SIMP BMS
11. Use the Teensy loader to reboot the SIMP BMS once Programmed, arrow pointing right
12. Using a Terminal program check all settings on the SIMP BMS, and correct as required

## Changelog

Version | Changes
V0.12 | Added info on Can Speeds information in Can chapter Possibility to change them in the Tesla settings charging menu
V0.13 | Connector 5 pinout updated IN3 is charge and not IN2
V0.14 | Shunt Trip output in ESSmode
V0.15 | Chevy Volt battery wiring
V0.16 | Mistubishi wiring info, output functions, common troubleshooting
V0.17 | Mistubishi wiring correction
V0.18 | Volt/Ampera wiring correction and General user Warning
V0.19 | -Updated Canbus -Added info on canbus expansion -Added info on wiring contactors or not
V0.20 | Updated Parameter Menu section
V0.21 | Updated ESS contactor Pinout AND BMW I3 connection info
V0.22 | Added more info on outputs and functions under ESS mode
V0.23 | Charges to ESS mode outputs, now also Low Switching Main contactor
V0.24 | Display Wiring Correction added info on Firmware update
V0.25 | Updated Links and updated intro pages.
V0.26 | Added more I3 wiring info
V0.27 | Correct can message info id 0x351

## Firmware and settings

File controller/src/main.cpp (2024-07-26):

#include "main.h"

#ifdef HOVER_SERIAL_FRONT
HardwareSerial HoverSerialFront(PA10, PA9); // USART1
#endif
#ifdef HOVER_SERIAL_REAR
HardwareSerial HoverSerialRear(PA3, PA2); // USART2
#endif

typedef struct {
    uint16_t start;
    int16_t  steer;
    int16_t  speed;
    uint16_t checksum;
} SerialCommand;

void setCommand(SerialCommand *command, int16_t steer, int16_t speed) {
    command->start = (int16_t) START_FRAME;
    command->steer = steer;
    command->speed = speed;
    command->checksum = command->start ^ command->steer ^ command->speed;
}

uint16_t flashInterval;
int16_t speedFeedback;
uint32_t lastSpeedFeedback;

void setup() {
    SerialUSB.begin();

    pinMode(PC13, OUTPUT);

    #ifdef HOVER_SERIAL_FRONT
    HoverSerialFront.begin(HOVER_SERIAL_BAUD);
    #endif

    #ifdef HOVER_SERIAL_REAR
    HoverSerialRear.begin(HOVER_SERIAL_BAUD);
    #endif

    pinMode(PIN_ACCEL_INPUT, INPUT);
    #ifdef PIN_BRAKE_INPUT
    pinMode(PIN_BRAKE_INPUT, INPUT);
    #endif

    #ifdef PIN_BALANCE_INPUT
    pinMode(PIN_BALANCE_INPUT, INPUT);
    #endif

    #ifdef PIN_REVERSE_INPUT
    pinMode(PIN_REVERSE_INPUT, INPUT_PULLUP);
    #endif
}

#ifdef HOVER_SERIAL_RX
typedef struct {
    uint16_t start;
    int16_t  cmd1;
    int16_t  cmd2;
    int16_t  speedR_meas;
    int16_t  speedL_meas;
    int16_t  batVoltage;
    int16_t  boardTemp;
    uint16_t cmdLed;
    uint16_t checksum;
} SerialRx;

typedef struct {
    uint8_t i = 0; // Index for new data pointer
    byte *p; // Pointer declaration for the new received byte. Probably not necessary, can just add index?
    byte prevByte; // For two-byte start marker detection
} SerialRxTemp;

SerialRx rxFront;
SerialRx rxRear;
SerialRxTemp rxTempFront;
SerialRxTemp rxTempRear;

void receive(const char *name, HardwareSerial *serial, SerialRx *rx, SerialRxTemp *rxTemp) {
    // Check for new data availability in the Serial buffer
    if (!serial->available()) {
        return;
    }

    byte *rxp = (byte*) rx; // Pointer to start byte of rx struct
    byte incomingByte = serial->read(); // Read the incoming byte
    uint16_t bufStartFrame = ((uint16_t) (incomingByte) << 8) | rxTemp->prevByte; // Construct the start frame

    // Copy received data
    if (bufStartFrame == START_FRAME) {	// Initialize if new data is detected
        rxTemp->i = 0;
        *(rxp + rxTemp->i++) = rxTemp->prevByte;
        *(rxp + rxTemp->i++) = incomingByte;
    } else if (rxTemp->i >= 2 && rxTemp->i < sizeof(SerialRx)) { // Save the new received data
        *(rxp + rxTemp->i++) = incomingByte;
    }

    // Check if we reached the end of the message
    if (rxTemp->i == sizeof(SerialRx)) {
        uint16_t checksum = rx->start ^ rx->cmd1 ^ rx->cmd2 ^ rx->speedR_meas ^ rx->speedL_meas ^ rx->batVoltage ^ rx->boardTemp ^ rx->cmdLed;

        // Check validity of the new data
        if (checksum == rx->checksum) {
            // Print data to built-in Serial
            speedFeedback = rx->speedL_meas + rx->speedR_meas / 2;
            lastSpeedFeedback = millis();
            #ifdef HOVER_SERIAL_RX_DEBUG
            Serial.print(name);
            Serial.print(" cmd1 ");   Serial.print(rx->cmd1);
            Serial.print(" cmd2 ");   Serial.print(rx->cmd2);
            Serial.print(" speedR "); Serial.print(rx->speedR_meas);
            Serial.print(" speedL "); Serial.print(rx->speedL_meas);
            Serial.print(" volt ");   Serial.print(rx->batVoltage);
            Serial.print(" temp ");   Serial.print(rx->boardTemp);
            Serial.print(" led ");    Serial.println(rx->cmdLed);
            #endif
        } else {
            #ifdef HOVER_SERIAL_RX_DEBUG
            Serial.println("Non-valid data skipped");
            #endif
        }

        // Reset the index (it prevents to enter in this if condition in the next cycle)
        rxTemp->i = 0;
    }

    // Update previous states
    rxTemp->prevByte = incomingByte;
}

void receiveAll() {
    #ifdef HOVER_SERIAL_FRONT
    receive("front", &HoverSerialFront, &rxFront, &rxTempFront);
    #endif
    #ifdef HOVER_SERIAL_REAR
    receive("rear", &HoverSerialRear, &rxRear, &rxTempRear);
    #endif
}
#endif

void sendSerial() {
    #ifdef PIN_BRAKE_INPUT
        const uint32_t brakeRaw = analogRead(PIN_BRAKE_INPUT);
        const int16_t brake = constrain(map(brakeRaw, INPUT_BRAKE_MIN, INPUT_BRAKE_MAX, 0, 1000), 0, 1000);
    #else
        const uint32_t brakeRaw = 0;
        const int16_t brake = 0;
    #endif

    const uint32_t accelRaw = analogRead(PIN_ACCEL_INPUT);
    const int16_t accel = constrain(map(accelRaw, INPUT_ACCEL_MIN, INPUT_ACCEL_MAX, 0, 1000), 0, 1000);

    int16_t speedCmd = 0;

    #ifdef PIN_REVERSE_INPUT
    const bool reverse = digitalRead(PIN_REVERSE_INPUT);
    if (lastSpeedFeedback < millis() - 500) {
        // Error
        Serial.println("error");
        speedCmd = 0;
    } else {
        speedCmd = accel - brake*2;
        if (reverse) {
            if (speedCmd >= 0) {
                // Should accelerate, meaning backwards speed
                speedCmd = -speedCmd;
            } else {
                // Should brake
                if (speedFeedback > 10) {
                    // Should send negative speed, no action needed
                } else if (speedFeedback < -10) {
                    speedCmd = -speedCmd;
                } else {
                    // Almost standstill, no action needed
                    speedCmd = 0;
                }
            }
        } else {
            if (speedCmd >= 0) {
                // Should accelerate, no action needed
            } else {
                // Should brake
                if (speedFeedback > 10) {
                    // Should send negative speed, no action needed
                } else if (speedFeedback < -10) {
                    speedCmd = -speedCmd;
                } else {
                    // Almost standstill, no action needed
                    speedCmd = 0;
                }
            }
        }
    }
    #else
    speedCmd = brake
            ? -map(brake, 0, 1000, 0, SPEED_BACKWARD_MAX)
            : map(accel, 0, 1000, 0, SPEED_FORWARD_MAX);
    #endif

    speedCmd = constrain(speedCmd, -SPEED_BACKWARD_MAX, SPEED_FORWARD_MAX);

    flashInterval = map(1000 - abs(speedCmd), 0, 1000, 25, 250);

    #ifdef INPUT_DEBUG
        Serial.print("accel ");
        Serial.print(accelRaw);
        Serial.print("->");
        Serial.print(accel);

        #ifdef PIN_BRAKE_INPUT
            Serial.print(" | brake ");
            Serial.print(brakeRaw);
            Serial.print("->");
            Serial.print(brake);
        #else
            Serial.print(" | brake disabled");
        #endif

        #ifdef PIN_REVERSE_INPUT
        Serial.print(" | reverse ");
        Serial.print(reverse);
        #endif

        Serial.print(" | speedCmd ");
        Serial.print(speedCmd);
    #endif

    #ifdef PIN_BALANCE_INPUT
    const uint32_t balanceRaw = analogRead(PIN_BALANCE_INPUT);
    const int16_t balance = constrain(map(balanceRaw, INPUT_BALANCE_MIN, INPUT_BALANCE_MAX, -BALANCE_CONST, BALANCE_CONST), -BALANCE_CONST, BALANCE_CONST);
    int16_t balanceFront, balanceRear;
    if (balance > 0) {
        balanceFront = BALANCE_CONST;
        balanceRear = BALANCE_CONST - balance;
    } else {
        balanceFront = BALANCE_CONST + balance;
        balanceRear = BALANCE_CONST;
    }
    Serial.print(" | balanceFront ");
    Serial.print(balanceFront);
    Serial.print(" | balanceRear ");
    Serial.print(balanceRear);
    #else
    const int16_t balanceFront = BALANCE_CONST, balanceRear = BALANCE_CONST;
    #endif

    SerialCommand command;

    #ifdef HOVER_SERIAL_FRONT
        int16_t speedCmdFront = (speedCmd * balanceFront) / BALANCE_CONST;
        #ifdef INPUT_DEBUG
            Serial.print(" | speedCmdFront ");
            Serial.print(speedCmdFront);
        #endif
        setCommand(&command, 0, speedCmdFront);
        HoverSerialFront.write((uint8_t *) &command, sizeof(SerialCommand));
    #endif

    #ifdef HOVER_SERIAL_REAR
        int16_t speedCmdRear = (speedCmd * balanceRear) / BALANCE_CONST;
        #ifdef INPUT_DEBUG
            Serial.print(" | speedCmdRear ");
            Serial.print(speedCmdRear);
        #endif
        setCommand(&command, 0, (speedCmdRear * speedCmd) / ADC_RESOLUTION);
        HoverSerialRear.write((uint8_t *) &command, sizeof(SerialCommand));
    #endif

    Serial.print(" | speedFeedback ");
    Serial.print(speedFeedback);

    Serial.println();
}

unsigned long lastSendTime = 0;
unsigned long lastFlashTime = 0;
uint32_t lastFlashState = 0;

void loop(void) {
    unsigned long timeNow = millis();

    #ifdef HOVER_SERIAL_RX
    receiveAll();
    #endif

    // Flash LED
    if (timeNow - lastFlashTime > flashInterval) {
        lastFlashTime = timeNow;
        lastFlashState = lastFlashState == HIGH ? LOW : HIGH;
        digitalWrite(PC13, lastFlashState);
    }

    if (timeNow - lastSendTime > SEND_INTERVAL) {
        lastSendTime = timeNow;
        sendSerial();
    }
}

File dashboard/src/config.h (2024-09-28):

#pragma once

// Vehicle parameters
#define WHEEL_CIRCUMFERENCE_MM 603
#define BAT_VOLT_EMPTY 3.3 * 12
#define BAT_VOLT_FULL 4.2 * 12

// Serial parameters
#define SERIAL_BAUD 115200

// Serial debug protocol parameters
#define CONTROL_SERIAL_BAUD 9600
// #define CONTROL_SERIAL_RX_DEBUG
// #define CONTROL_SERIAL_RX_DEBUG_RAW
// #define CONTROL_SERIAL_TX_DEBUG
#define CONTROL_SERIAL_WORKING_TIMEOUT_MS 30000 // TODO lower when it works

// Menu parameters
// #define ENABLE_SETTINGS
#define SAVE_DEBUG
#define SAVE_INTERVAL 2000 // TODO lower when it works
#define HOME_REFRESH_INTERVAL 200 // TODO lower when it works

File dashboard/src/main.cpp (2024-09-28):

#include "main.h"

Bounce2::Button switchButton = Bounce2::Button();
Bounce2::Button actionButton = Bounce2::Button();

static Menu menu = (Menu) ((int) MENU_COUNT - 1); // initial state last menu means first menu is actual first state

Controller cF("front", PA3, PA2); // front motor controller, USART2
Controller cR("rear", PA10, PA9); // rear motor controller, USART1

static int16_t avgFeedbackRpm() {
    if (cR.working() && cF.working()) {
        return (cR.feedbackSPD_AVG + cF.feedbackSPD_AVG) / 2;
    } else if (cR.working()) {
        return cR.feedbackSPD_AVG;
    } else if (cF.working()) {
        return cF.feedbackSPD_AVG;
    } else {
        return 0;
    }
}

static int16_t totalFeedbackCurrent() {
    return (cR.working() ? cR.feedbackDC_CURR : 0) + (cF.working() ? cF.feedbackDC_CURR : 0);
}

static int16_t avgFeedbackBatVoltage() {
    if (cR.working() && cF.working()) {
        return (cR.feedbackBATV + cF.feedbackBATV) / 2;
    } else if (cR.working()) {
        return cR.feedbackBATV;
    } else if (cF.working()) {
        return cF.feedbackBATV;
    } else {
        return 0;
    }
}

static void drawHome() {
    // If both controllers have no working feedback, there is no data we can show
    if (!cR.working() && !cF.working()) {
        drawStrFull("no comms");
        return;
    }

    const int16_t rpm = avgFeedbackRpm();
    const float current = totalFeedbackCurrent() * 1e-2f;
    const float voltage = avgFeedbackBatVoltage() * 1e-2f;

    char speedText[16], powerText[16], batText[16];

    // Speed
    const int8_t speed = (uint8_t) (6e-5f * rpm * WHEEL_CIRCUMFERENCE_MM);
    snprintf(speedText, 16, "%i km/h", speed);

    // Power
    const float power = current * voltage;
    snprintf(powerText, 16, "%iA %iW", (int) current, (int) power);

    // Battery, or error message if one of the two controllers can't be reached
    if (!cR.working()) {
        strcpy(batText, "err rear");
    } else if (!cF.working()) {
        strcpy(batText, "err front");
    } else {
        const float batVoltage = voltage;
        const uint8_t batPercent = (uint8_t) ((voltage - BAT_VOLT_EMPTY) * 100 / (BAT_VOLT_FULL - BAT_VOLT_EMPTY));
        snprintf(batText, 16, "%.1fV %i%%", batVoltage, batPercent);
    }

    // Write to screen
    u8g2.clearBuffer();
    drawStrCentered(CH, speedText);
    drawStrCentered(CH*2, powerText);
    drawStrCentered(CH*3, batText);
    u8g2.sendBuffer();
}

#ifdef ENABLE_SETTINGS
void drawDrive() {
    u8g2.clearBuffer();
    drawSettingHeader("drive");
    u8g2.drawStr(0, CH*2, "FOC SIN");
    switch(param_get(cR.pCtrlTyp)) {
        case CTRL_TYP_FOC:
            u8g2.drawStr(0, CH*3, "\xaf\xaf\xaf");
            u8g2.drawStr(0, CH*3 + 4, "smooth");
            break;
        case CTRL_TYP_SIN:
            u8g2.drawStr(0, CH*3, "    \xaf\xaf\xaf");
            u8g2.drawStr(0, CH*3 + 4, "faster");
            break;
    }
    u8g2.sendBuffer();
}

void actionDrive() {
    switch(param_get(cR.pCtrlTyp)) {
        case CTRL_TYP_FOC:
            param_set(cR.pCtrlTyp, CTRL_TYP_SIN);
            param_set(cR.pCtrlMod, CTRL_MOD_VLT);
            param_set(cF.pCtrlTyp, CTRL_TYP_SIN);
            param_set(cF.pCtrlMod, CTRL_MOD_VLT);
            break;
        case CTRL_TYP_SIN:
            param_set(cR.pCtrlTyp, CTRL_TYP_FOC);
            param_set(cR.pCtrlMod, CTRL_MOD_TRQ);
            param_set(cF.pCtrlTyp, CTRL_TYP_FOC);
            param_set(cF.pCtrlMod, CTRL_MOD_TRQ);
            break;
    }

    drawDrive();
}

void drawFieldWeak() {
    u8g2.clearBuffer();

    switch (param_get(cR.pCtrlTyp)) {
        case CTRL_TYP_SIN:
            drawSettingHeader("angle");
            u8g2.drawStr(0, CH*2, "0 15 30 45");
            switch(param_get(cR.pPhaAdvMax)) {
                case  0: u8g2.drawStr(0, CH*3, "\xaf"); break;
                case 15: u8g2.drawStr(0, CH*3, "  \xaf\xaf"); break;
                case 30: u8g2.drawStr(0, CH*3, "     \xaf\xaf"); break;
                case 45: u8g2.drawStr(0, CH*3, "        \xaf\xaf"); break;
            }

            u8g2.drawStr(0, CH*3 + 4, param_get(cR.pPhaAdvMax) ? "more speed" : "standard");
            break;
        case CTRL_TYP_FOC:
            drawSettingHeader("fi weak");
            u8g2.drawStr(0, CH*2, "0 2A 5A 8A");
            switch (param_get(cR.pFiWeakMax)) {
                case 0: u8g2.drawStr(0, CH*3, "\xaf"); break;
                case 2: u8g2.drawStr(0, CH*3, "  \xaf\xaf"); break;
                case 5: u8g2.drawStr(0, CH*3, "     \xaf\xaf"); break;
                case 8: u8g2.drawStr(0, CH*3, "        \xaf\xaf"); break;
            }

            u8g2.drawStr(0, CH*3 + 4, param_get(cR.pFiWeakMax) ? "more power" : "disabled");
            break;
    }

    u8g2.sendBuffer();
}

void actionFieldWeak() {
    int16_t newValue;
    switch (param_get(cR.pCtrlTyp)) {
        case CTRL_TYP_SIN:
            newValue = (param_get(cR.pPhaAdvMax) + 15) % 60;
            param_set(cF.pPhaAdvMax, newValue);
            param_set(cR.pPhaAdvMax, newValue);
            param_set(cF.pFiWeakEna, newValue > 0);
            param_set(cR.pFiWeakEna, newValue > 0);
            break;
        case CTRL_TYP_FOC:
            switch(param_get(cR.pFiWeakMax)) {
                case 0: newValue = 2; break;
                case 2: newValue = 5; break;
                case 5: newValue = 8; break;
                case 8: newValue = 0; break;
            }
            param_set(cF.pFiWeakMax, newValue);
            param_set(cR.pFiWeakMax, newValue);
            param_set(cF.pFiWeakEna, newValue > 0);
            param_set(cR.pFiWeakEna, newValue > 0);
            break;
    }

    drawFieldWeak();
}

void drawCurrent(Controller &c) {
    u8g2.clearBuffer();
    drawSettingHeader("current");
    u8g2.drawStr(0, CH*2, "5A 10A 15A");
    switch(param_get(c.pIMotMax)) {
        case 5:  u8g2.drawStr(0, CH*3, "\xaf\xaf"); break;
        case 10: u8g2.drawStr(0, CH*3, "   \xaf\xaf\xaf"); break;
        case 15: u8g2.drawStr(0, CH*3, "       \xaf\xaf\xaf"); break;
    }
    u8g2.drawStr(0, CH*3 + 4, c.name);
    u8g2.sendBuffer();
}

void actionCurrent(Controller &c) {
    int16_t newCurrent = param_get(c.pIMotMax) + 5;
    if (newCurrent > 15) newCurrent = 5;
    param_set(c.pIMotMax, newCurrent);
    drawCurrent(c);
}

void drawSaving() {
    u8g2.clearBuffer();
    u8g2.drawStr(0, CH, "saving");
    // Later, the save loop will add more information about which parameter is saving
    u8g2.sendBuffer();
}
#endif
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

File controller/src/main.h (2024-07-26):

#include <Arduino.h>

// Pinout
#define PIN_ACCEL_INPUT PA0
#define PIN_BRAKE_INPUT PA1
// #define PIN_REVERSE_INPUT PA2

// Can only be used in torque mode, otherwise wheels will turn at different speeds
// #define PIN_BALANCE_INPUT PB0

/*
 * Connect RX to TX on hoverboard, left sideboard connector next to positive
 * Connect TX to RX on hoverboard, left sideboard connector next to negative
 * RX=red/brown TX=green/blue
 */

// Calibrate analog inputs
#define INPUT_DEBUG
#define INPUT_ACCEL_MIN     300
#define INPUT_ACCEL_MAX     670
#define INPUT_BRAKE_MIN     300
#define INPUT_BRAKE_MAX     800
#define INPUT_BALANCE_MIN   3
#define INPUT_BALANCE_MAX   1020

// Safety limit
#define SPEED_FORWARD_MAX   1000
#define SPEED_BACKWARD_MAX  500

// Hoverboard firmware has 5 ms loop, so any faster does not make sense.
#define SEND_INTERVAL       50
// At 8 bytes per message with 19200 baud max 300 messages per second can be sent (every 3ms). Hoverboard firmware has 5ms loop so faster does not make sense. Arduino firmware has fixed 10ms loop.
#define HOVER_SERIAL_BAUD   9600        // Baud rate for HoverSerial (used to communicate with the hoverboard)
#define HOVER_SERIAL_RX                 // Receive data from HoverSerial
// #define HOVER_SERIAL_RX_DEBUG
#define HOVER_SERIAL_FRONT
// #define HOVER_SERIAL_REAR
#define START_FRAME         0xABCD     	// Start frame definition for reliable serial communication

#define BALANCE_CONST 16 // 1000 * 16 just fits in int16_t

#if defined(PIN_REVERSE_INPUT) && !defined(HOVER_SERIAL_RX)
    #error Serial RX must be enabled to use reverse input
#endif

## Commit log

2024-07-26 Set correct character height
    [screen.h]
2024-07-26 Add 3D printed parts
    [achterlicht.scad, hoofdzekeringdoos.scad, spatbord.scad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]
2024-07-26 Adjust ADC parameters
2024-07-26 Dashboard serial communication bug fixes
    [main.cpp, main.h]
2024-07-27 another rewrite, with a confusing issue still remaining
    [main.cpp, main.h, params.h]
2024-07-27 Fix double definition by making function inline
    [params.h]
2024-07-28 tekst op hoofdzekeringdoos
    [hoofdzekeringdoos.scad]
2024-07-30 lower motor current
2024-07-30 Failed attempts at fixing dashboard
    [config.h, main.cpp, main.h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]
2024-09-24 Fix missing variable in printf
2024-09-25 Meer ruimte rondom as
    [spatbord.scad]
2024-09-26 decrease motor current
2024-09-28 scherm is iets kleiner
    [stuurscherm.scad]
2024-09-28 controller doos
    [controller.scad]
2024-09-28 Disable settings until fixed
    [config.h, main.cpp, main.h]
2025-01-20 highlight weg
    [controller.scad]
2025-02-28 BMS documenten
